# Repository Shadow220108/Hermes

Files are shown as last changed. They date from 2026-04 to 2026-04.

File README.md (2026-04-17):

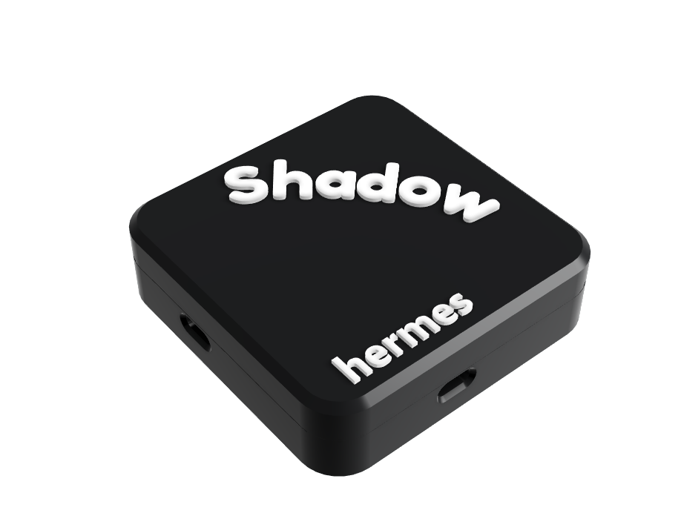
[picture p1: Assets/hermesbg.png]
hermes
 

## Hermes  
Hermes is a 4-port USB HUB, using FE1.1s. It has 3 USB-A and 1 USB-C downstream ports, and 1 USB-C upstream port for connecting to the computer. It is a highly integrated, low-power USB 2.0 high-speed bus-powered USB HUB supporting upto 480 MHz signals.

This is my first iteration of a USB Hub using the FE1.1s IC. I plan to make future versions with more ports and different ICs, It was built to solve the scarcity of ports on my miserable laptop 

| Animation |
| --- | 
| Animation |

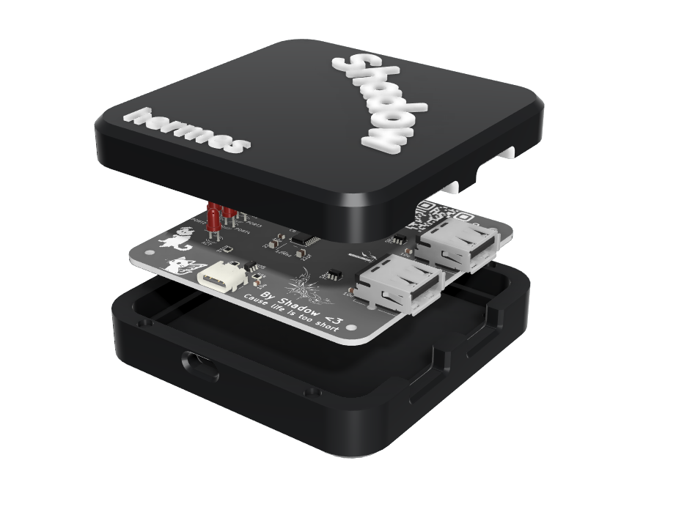
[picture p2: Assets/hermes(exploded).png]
exploded
 

All the components will be hand soldered by me, and the case will be 3D Printed!
The bottom and top cases will be attached together with 4mm magnets!

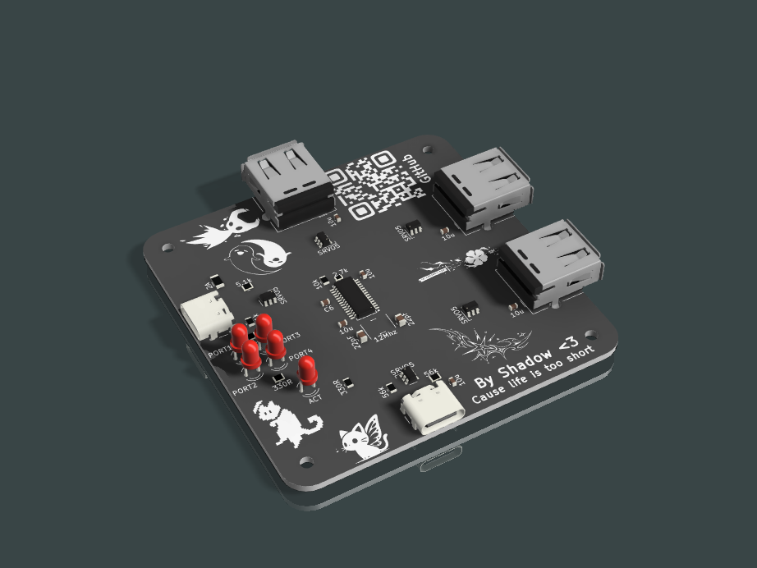
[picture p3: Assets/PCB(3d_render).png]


The PCB was made in KiCAD (an open-source software), which uses a 4-layer board with a (5V GND 5V GND) stackup to provide a clean GND plane for data signals.
It can support up to 480MHz.

## PCB
| All layers |
| --- | 
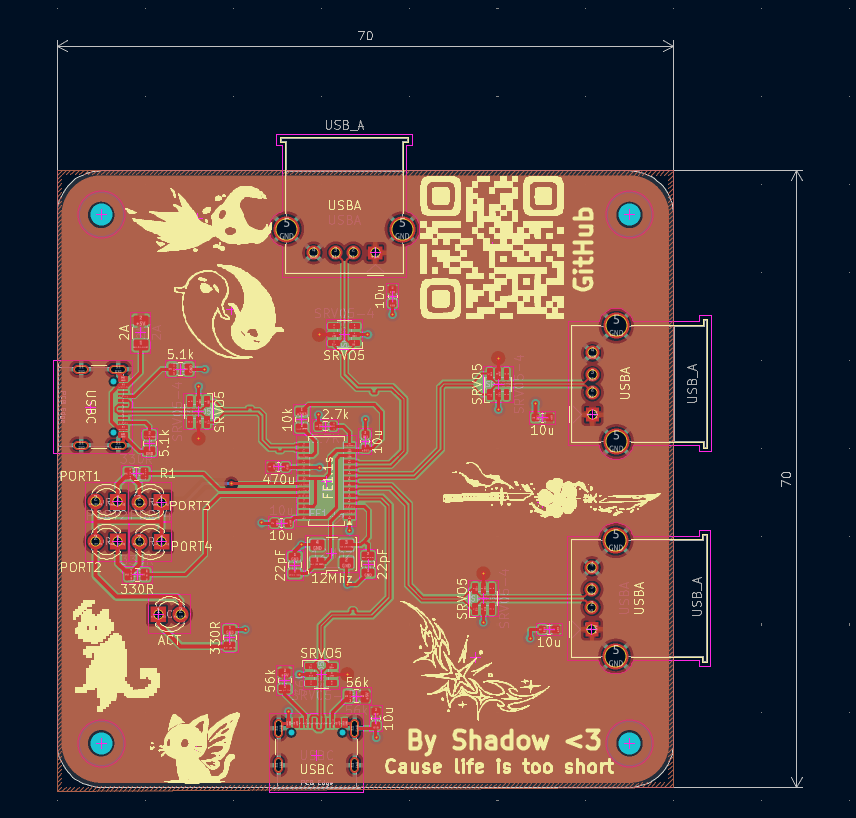
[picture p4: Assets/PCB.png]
|  |

| Without Zones  |
| --- | 
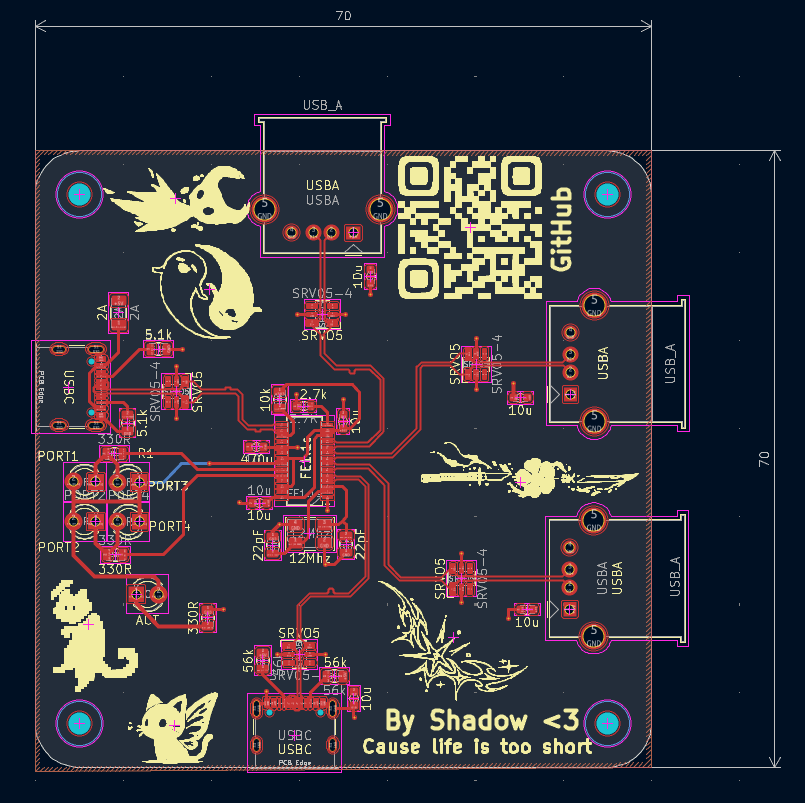
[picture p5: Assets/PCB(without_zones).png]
|  |  

## Schematics  
| Main IC  |
| --- | 
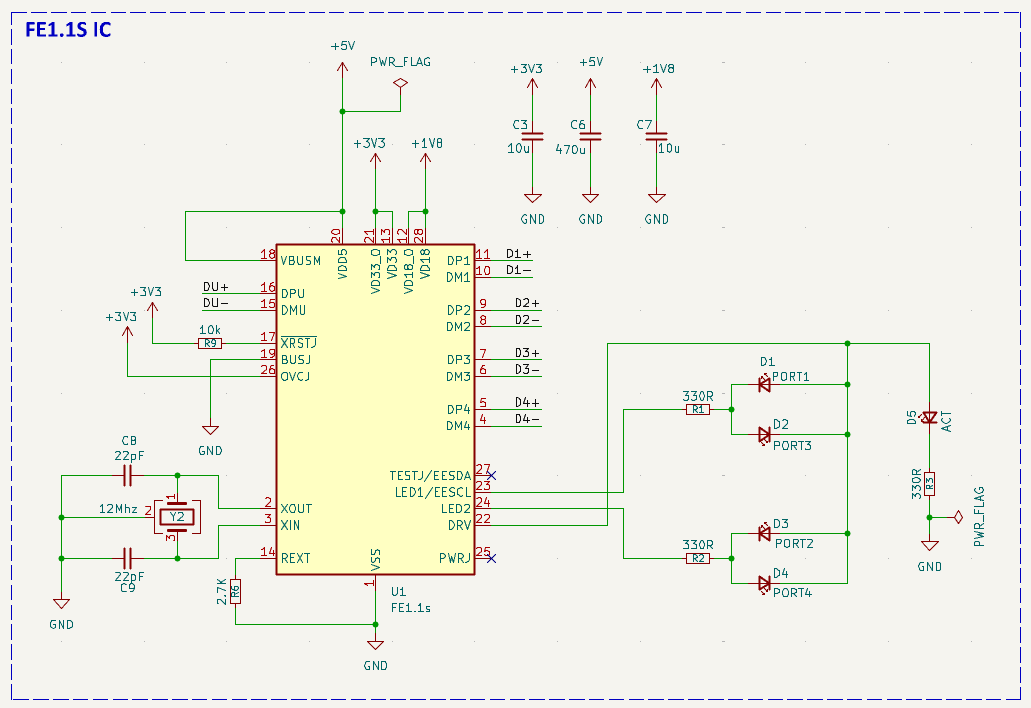
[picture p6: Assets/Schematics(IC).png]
Schematics
|  |   

| Upstream Port |
| --- | 
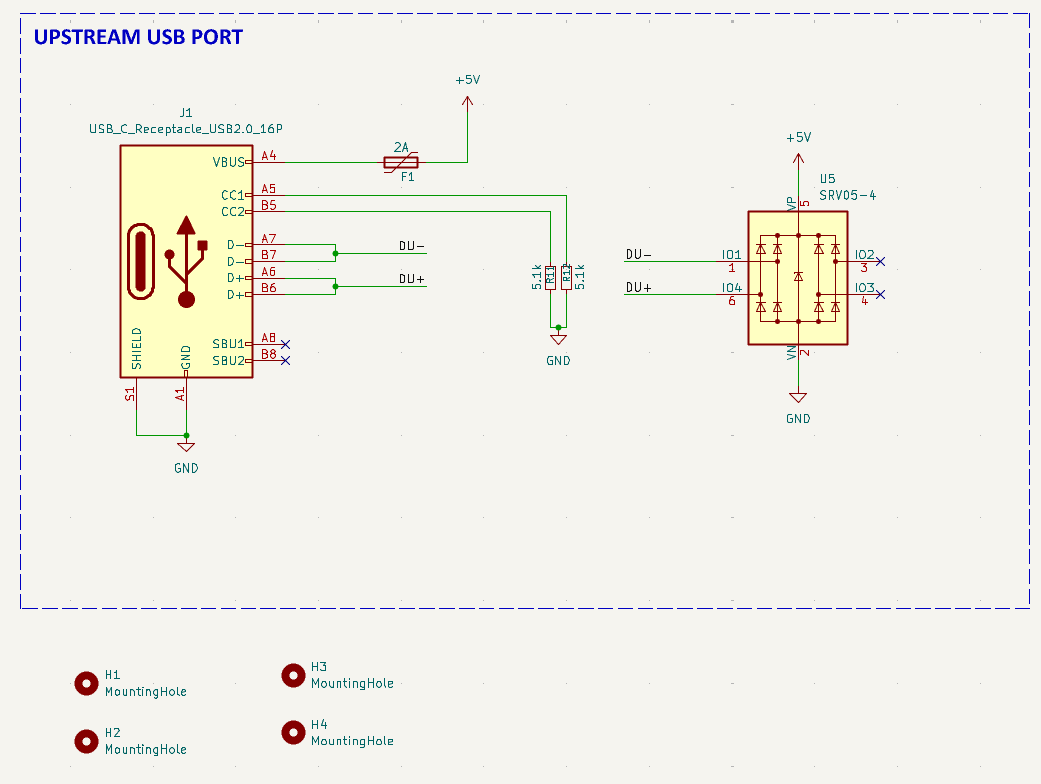
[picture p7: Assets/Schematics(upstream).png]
Schematics
|  

| Downstream Ports |
| --- | 
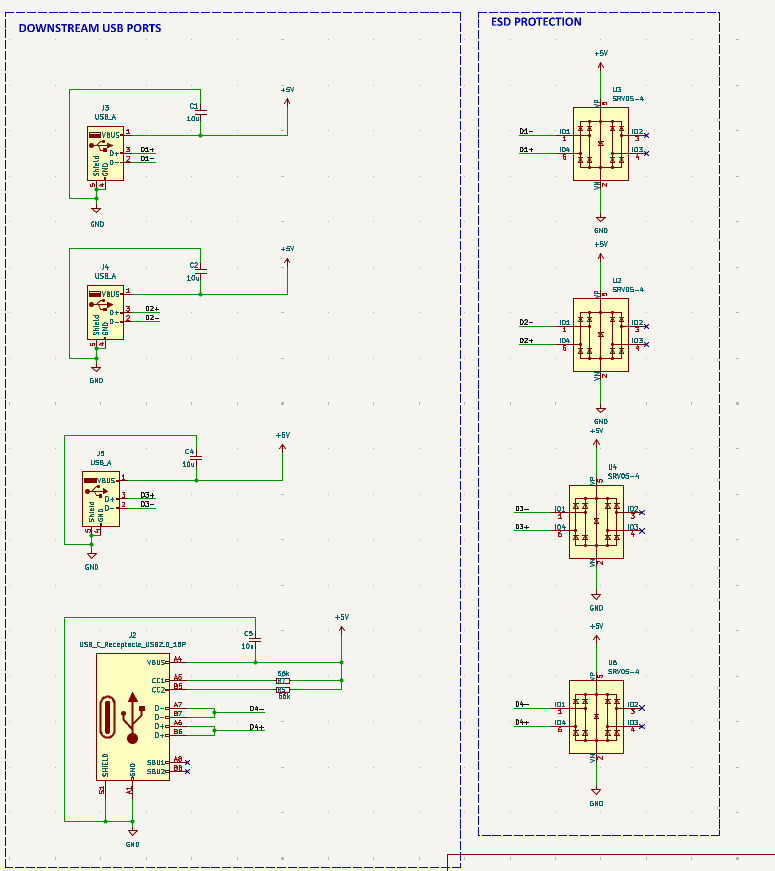
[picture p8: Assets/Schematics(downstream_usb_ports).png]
Schematics
|    

## Simple Build Guide :3  
1. Order the PCBs and the components 
2. Assemble the PCB ( Make sure to have appropriate tools such as a hotplate or a reflow station )
3. Get the case 3D printed!
4. Attach the top and bottom case using 4x1.5mm magnets
5. Start using!!

## BOM   
|Name |Purpose |Quantity|Total Cost (USD)|Link |Distributor|
|---|---|---|---|---|---|
|PCBs |PCB |5 |14.00 | |jlcpcb |
|2A Polyfuse |fuse |1 |0.20 |[link](https://robu.in/product/1812l200-12dr-littelfuse-1812l200-12dr-resettable-fuse-pptc-1812-4532-metric-polyswitch-1812l-series-12-vdc-2-a-3-5-a-2-s/)|robu.in |
|12 MHz crystal |crystal oscillator |1 |0.50 |[link](https://robu.in/product/ysx531sl-12mhz-20pf-10ppm-4pad-smd-smt-crystal/) |robu.in |
|10k ohm resistor |resistor |30 |0.10 |[link](https://robu.in/product/rc0805jr-0710kl-yageo-res-thick-film-0805-10k-ohm-5-0-125w1-8w-%C2%B1100ppm-c-pad-smd-t-r/) |robu.in |
|2.7k resistor |resistor |100 |0.10 |[link](https://robu.in/product/ac0603fr-7w2k7l-yageo-res-2-7k-ohm-1-1-5w-0603/) |robu.in |
|5.1k ohm resistor|resistor |100 |0.10 |[link](https://robu.in/product/rc0805jr-075k1l-yageo-smd-chip-resistor-5-1-kohm-%C2%B1-5-125-mw-0805-2012-metric-thick-film-general-purpose/) |robu.in |
|56k ohm resistor |resistor |100 |0.10 |[link](https://robu.in/product/rc0805fr-0756kl-yageo-res-thick-film-0805-56k-ohm-1-0-125w1-8w-%c2%b1100ppm-c-pad-smd-t-r/) |robu.in |
|330 ohm resistors|Resistors |100 |1.50 |[link](https://www.amazon.in/Resistor-330-Ohms-0805-pack/dp/B0G1TF1GP) |Amazon |
|10uF Capacitors  |Decoupling caps |10 |0.10 |[link](https://robu.in/product/0603x106k160nt-fh-16v-10uf-x5r%c2%b110-0603-multilayer-ceramic-capacitors-mlcc-smd-smt-rohs/) |robu.in |
|SRVO-5 |ESD Protection |10 |1.50 |[link](https://robu.in/product/srv05-4mr6t1g-onsemi-srv05-4mr6t1g-esd-protection-device-17-5-v-tsop-6-pins-300-w/) |robu.in |
|USB-A connector  |downstream ports |5 |0.50 |[link](https://www.flyrobo.in/usb-female-90-usb-socket?tracking=ads) |flyrobo.in |
|USB-C connector  |upstream and downstream ports|2 |0.20 |[link](https://www.flyrobo.in/usb-3.1-type-c-16-pin-onboard-horizontal-smt-female-connector?tracking=ads) |flyrobo.in |
|FE1.1s |Main IC |1 |1.10 |[link](https://robu.in/product/fe1-1s-bsop28bcn-terminus-tech-ssop-28-150mil-usb-converters-rohs/) |robu.in |
|Shipping | | |4.00 | | |
| | |Total |24.00 USD | | |

| ZINE |  
| --- |  
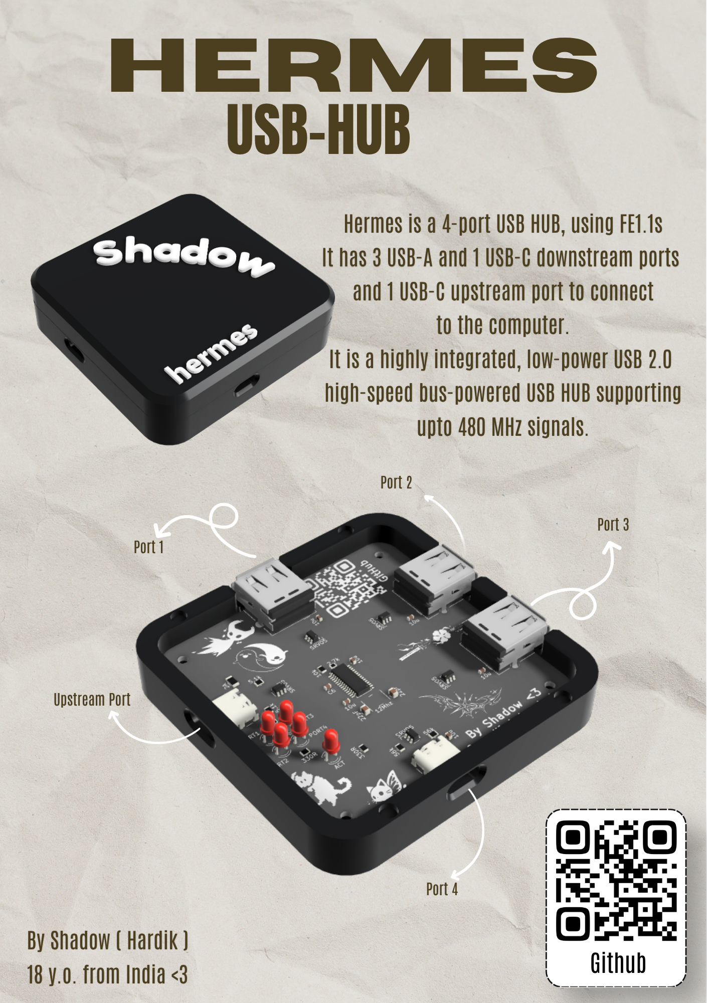
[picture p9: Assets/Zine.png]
Zine
|  |

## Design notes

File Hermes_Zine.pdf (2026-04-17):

# HERMES

# USB-HUB

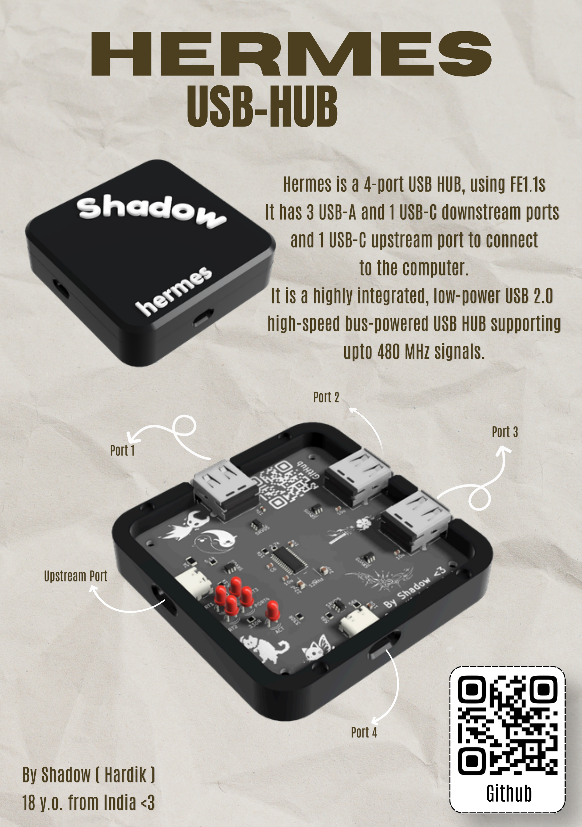
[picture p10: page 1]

Hermes is a 4-port USB HUB, using FE1.1s It has 3 USB-A and 1 USB-C downstream ports and 1 USB-C upstream port to connect to the computer.
It is a highly integrated, low-power USB 2.0 high-speed bus-powered USB HUB supporting upto 480 MHz signals.

Hermes is a 4-port USB HUB, using FE1.1s It has 3 USB-A and 1 USB-C downstream ports and 1 USB-C upstream port to connect to the computer.
It is a highly integrated, low-power USB 2.0 high-speed bus-powered USB HUB supporting upto 480 MHz signals.
Port 1 | Port 2 Upstream Port | Port 3 Port 4

Github

By Shadow ( Hardik )
18 y.o. from India <3

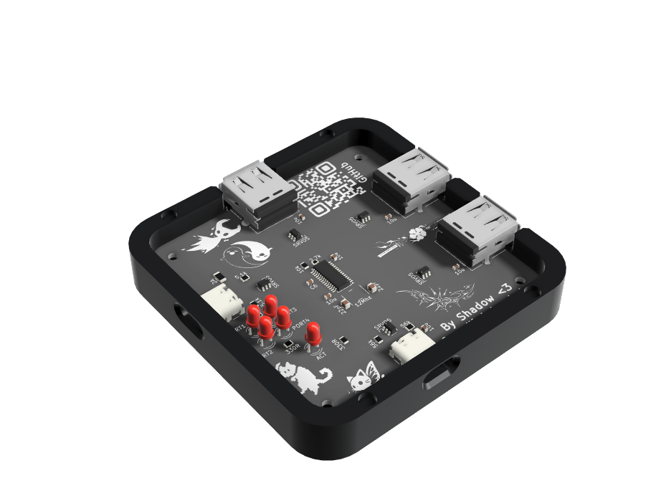
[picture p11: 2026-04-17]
Assets/hermes_without_topbg.png

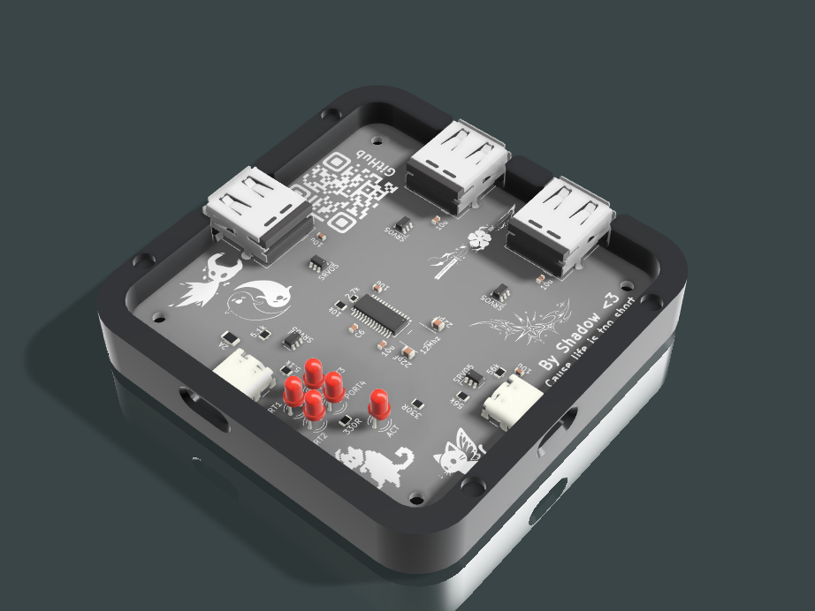
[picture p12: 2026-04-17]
Assets/hermes(without_top).png

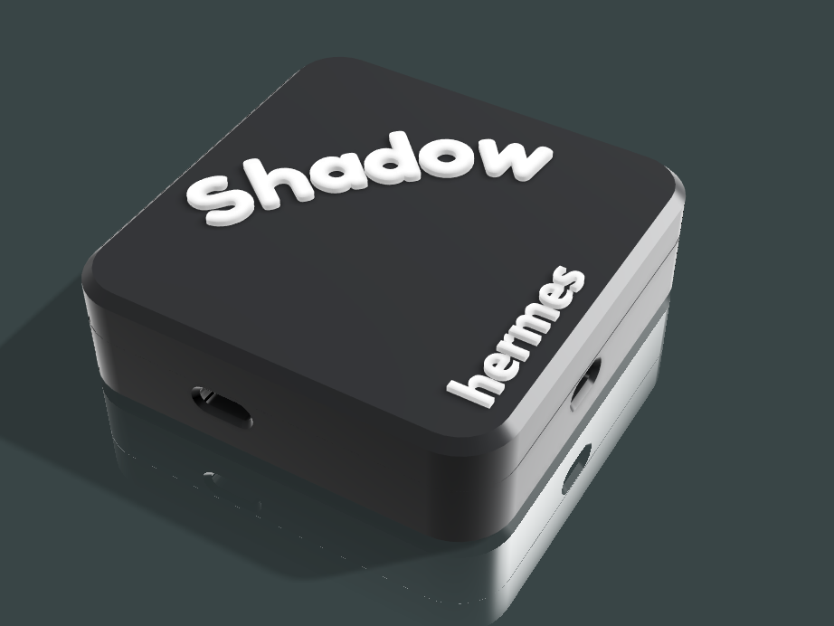
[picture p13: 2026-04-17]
Assets/hermes.png

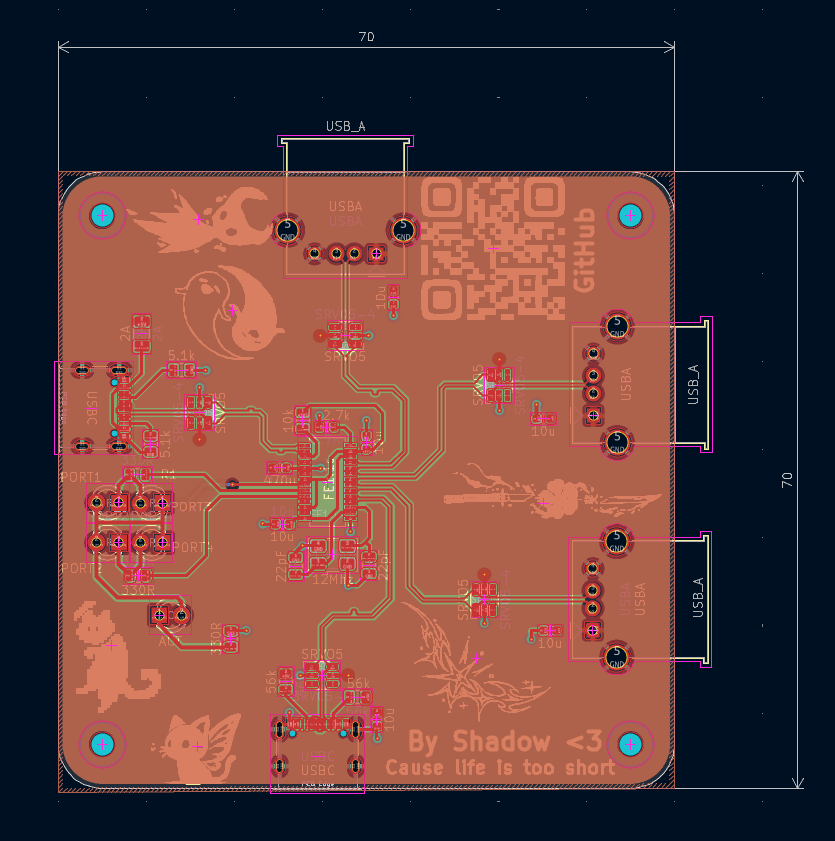
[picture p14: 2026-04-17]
Assets/PCB(all)_ayers).png

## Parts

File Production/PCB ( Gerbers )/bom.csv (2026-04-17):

Designator | Footprint | Quantity | Value | LCSC Part #
10K | 0805 | 1 | 10k
10U_6, 10U_5, 10U_4, 10U_3, 10U_2, 10U, 470U | 0603 | 7 | 10u
12MHZ | Crystal_SMD_5032-4Pin_5.0x3.2mm | 1 | 12Mhz
2.7K | 0603 | 1 | 2.7K
22PF_2, 22PF | 0805 | 2 | 22pF
2A | 1206 | 1 | 2A
330R_2, 330R, R1 | 0805 | 3 | 330R
5.1K_2, 5.1K | 0805 | 2 | 5.1k
56K_2, 56K | 0805 | 2 | 56k
ACT | LED_D3.0mm | 1 | ACT
FE1.1S | SSOP-28_3.9x9.9mm_P0.635mm | 1 | FE1.1s
PORT1 | LED_D3.0mm | 1 | PORT1
PORT2 | LED_D3.0mm | 1 | PORT2
PORT3 | LED_D3.0mm | 1 | PORT3
PORT4 | LED_D3.0mm | 1 | PORT4
SRVO5_5, SRVO5_4, SRVO5_3, SRVO5_2, SRVO5 | SOT-23-6-routable | 5 | SRV05-4
USBA_3, USBA_2, USBA | USB_A_Molex_67643_Horizontal | 3 | USB_A
USBC_2, USBC | USB_C_Receptacle_GCT_USB4105-xx-A_16P_TopMnt_Horizontal | 2 | USB_C_Receptacle_USB2.0_16P

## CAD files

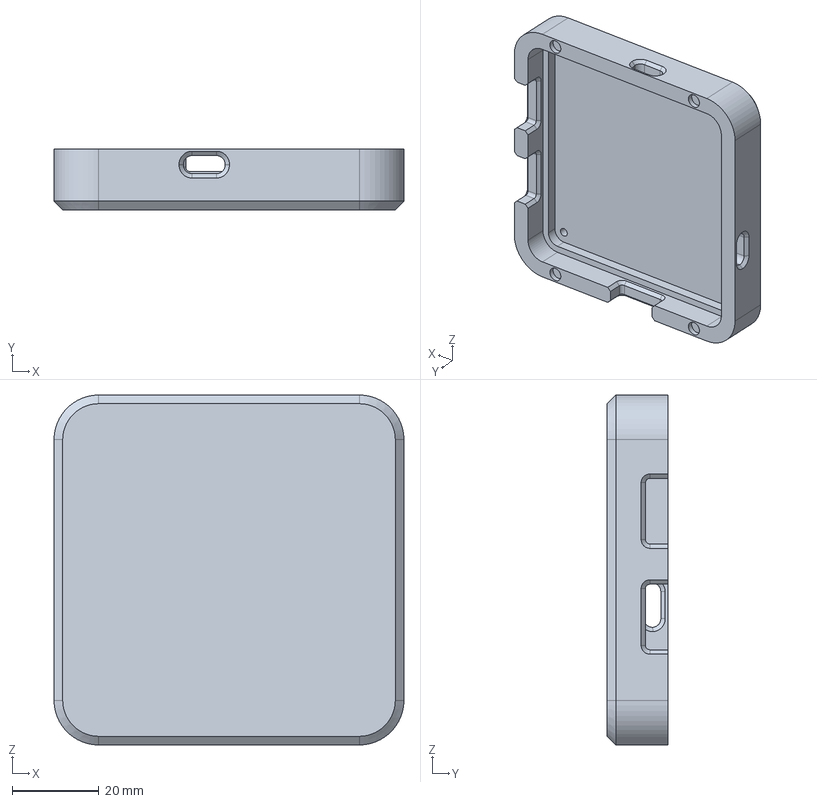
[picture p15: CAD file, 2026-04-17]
CAD/hermes(bottom).step
80.6 x 14.0 x 80.6 mm

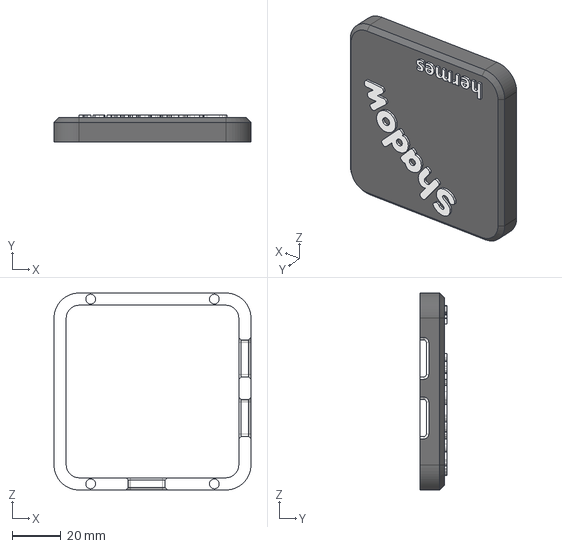
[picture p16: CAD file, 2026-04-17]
CAD/hermes(top).step
80.6 x 11.0 x 80.6 mm

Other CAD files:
Production/STL/hermes(bottom).stl
Production/STL/hermes(top).stl
